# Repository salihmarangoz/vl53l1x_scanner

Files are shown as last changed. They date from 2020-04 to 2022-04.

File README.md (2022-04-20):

# VL53L1X Scanner (Abandoned Project)

   * [VL53L1X Scanner (Abandoned Project)](#vl53l1x-scanner-abandoned-project)
      * [1. Introduction](#1-introduction)
      * [2. Making the Scanner](#2-making-the-scanner)
      * [3. Installing the Software](#3-installing-the-software)
      * [4. Running](#4-running)
      * [5. Notes](#5-notes)
      * [6. References](#6-references)

## 1. Introduction

**Note:** This project is abandoned. The code works well but the hardware selection is poor. Single VL53L1X is too slow and stepper motor has problems. Althought, the code can be used as a reference.

This is my DIY laser scanner project that I designed in quarantine days of covid-19.  I aim to demonstrate the capabilities of VL53L1X range finder sensor and design a 2D/3D scanner and depth camera.

**Features:**

- ROS Driver
- 2D and 3D scanning mode (~1500 step in horizontal ~270 deg fov / 13 step in vertical ~27 deg fov)
- Resets stepper motor position to 0 when the driver is terminated
- Depth camera mode
- Stepper One Phase/Two Phase Mode
- Adaptive Scanning
  - Adaptive stepper resolution based on the measurement

## 2. Making the Scanner

Materials should be placed on to the breadboard and connections should be made as it is shown in the pictures below:

**Requirements:**

- VL53L1X  ToF Laser Distance Sensor
- 28BYJ-48 Stepper Motor and its driver board (ULN2003APG)
- A header for stepper motor (I used servo motor header)
- Arduino UNO
- Breadboard & Jumper Cables
- Hot glue & Adhesive Tape
- PC and USB Cable for Arduino (Will be used in `Installing the Software` section)

**Connection Diagram:**

- (Blue) `Arduino D9` **<=>** `Stepper motor driver IN1`
- (Blue) `Arduino D10` **<=>** `Stepper motor driver IN2`
- (Blue) `Arduino D11` **<=>** `Stepper motor driver IN3`
- (Blue) `Arduino D12` **<=>** `Stepper motor driver IN4`
- (Cyan) `Arduino SDA` **<=>** `VL53L1X SDA`
- (Cyan) `Arduino SCL` **<=>** `VL53L1X SCL`
- (Red) `Arduino 5V` **<=>** `Stepper Motor Driver 5V` **<=>** `VL53L1X VIN`
- (Black) `Arduino GND` **<=>** `Stepper Motor Driver GND` **<=>** `VL53L1X GND`
- (Colorful) `Stepper Motor Driver` **<=>** `Stepper Motor`

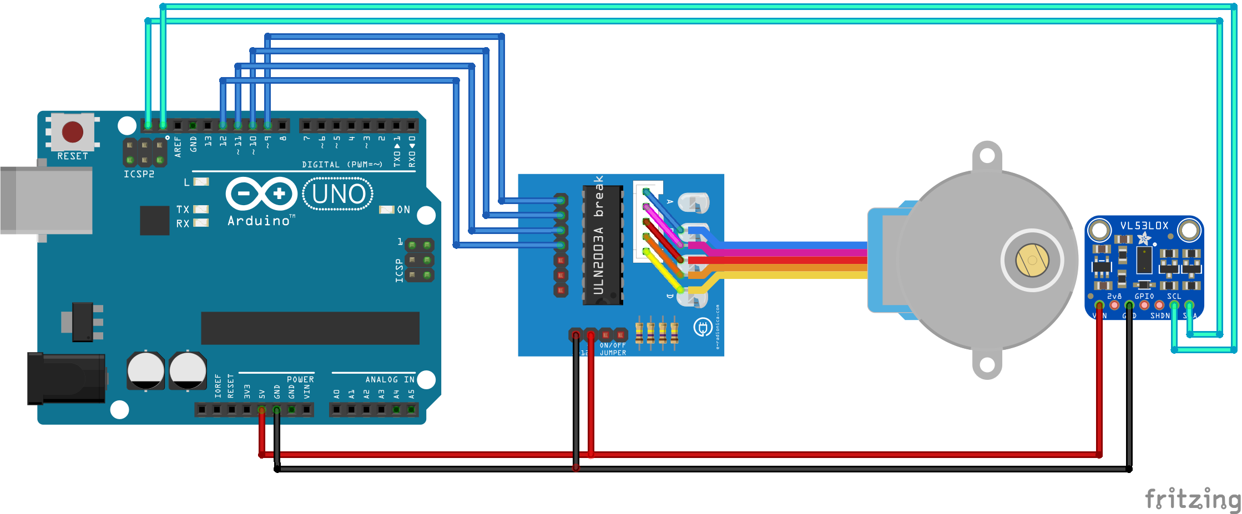
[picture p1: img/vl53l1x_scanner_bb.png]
vl53l1x_scanner_bb


**Result:**

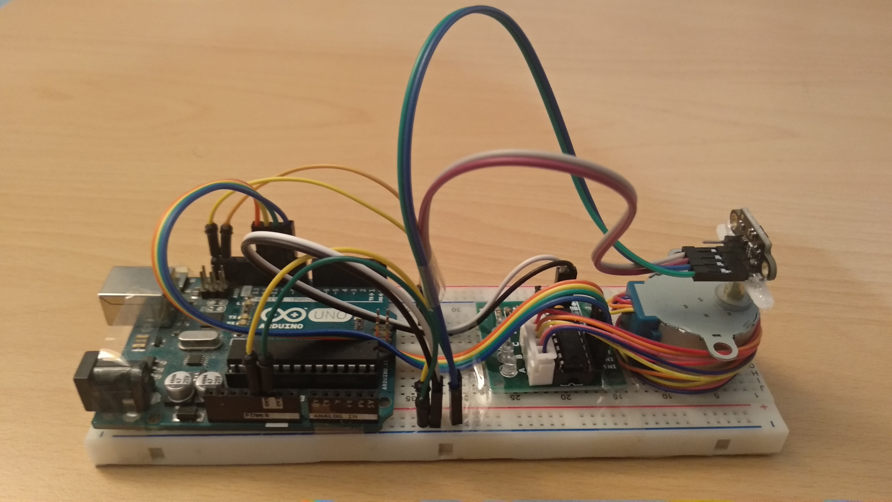
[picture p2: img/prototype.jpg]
prototype


## 3. Installing the Software

**Requirements:**

- Ubuntu 18.04 & ROS Melodic

- Arduino IDE 1.8.12
- VL53L1X API (https://www.st.com/en/embedded-software/stsw-img007.html#get-software)

**Installing:**

- Add user to dialout group then restart the PC:

```bash
$ sudo adduser $USER dialout
```

- Clone the project into `catkin_ws`:

```bash
$ mkdir -p ~/catkin_ws/src
$ cd ~/catkin_ws/src
$ git clone https://github.com/salihmarangoz/vl53l1x_scanner.git
```

- Compile the project:

```bash
$ cd ~/catkin_ws
$ catkin_make # or "catkin build"
```

- Extract the API folder (`vl53l1_api`) into `~/Arduino/libraries/` (Link in the requirements section)
- Upload the Arduino code using Arduino IDE: `~/catkin_ws/src/vl53l1x_scanner/arduino_code/vl53l1x_scanner_arduino/vl53l1x_scanner_arduino.ino`

## 4. Running

- Before running the systems, calibration process must be done if the laser is not faced forward:

```bash
$ cd ~/catkin_ws/src/vl53l1x_scanner/script/
# Positive for counter-clockwise or negative for clockwise rotation.
# The value "+100" is an example for positive rotation. Try "-100".
# As a result, laser should be facing forward.
# NOTE: May not work at the first try.
$ ./calibrate.sh /dev/ttyACM0 +100   
```

- Run the scanner driver:

```bash
$ source ~/catkin_ws/devel/setup.bash

# TO START THE DRIVER SELECT ONE:
$ roslaunch vl53l1x_scanner start_2d_laserscan.launch
$ roslaunch vl53l1x_scanner start_2d_pointcloud.launch # <- preffered
$ roslaunch vl53l1x_scanner start_3d_pointcloud.launch
$ roslaunch vl53l1x_scanner start_depth_camera.launch

# OR;

# TO INVESTIGATE PRE-RECORDED BAGS SELECT ONE:
$ roslaunch vl53l1x_scanner bag_2d.launch
$ roslaunch vl53l1x_scanner bag_3d.launch
```

- Run RViz:

```bash
$ roslaunch vl53l1x_scanner rviz.launch
```

## 5. References

- Stepper Driver Documentation: http://eeshop.unl.edu/pdf/Stepper+Driver.pdf
- VL53L1X ROI Documentation: https://www.st.com/resource/en/application_note/dm00516219-using-the-programmable-region-of-interest-roi-with-the-vl53l1x-stmicroelectronics.pdf
- Stepper and its Driver Fritzing Files: https://github.com/e-radionicacom/e-radionica.com-Fritzing-Library-parts-

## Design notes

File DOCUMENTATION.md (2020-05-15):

# VL53L1X Scanner Code Documentation

UNDER CONSTRUCTION!

### 1. Adaptive Scan Resolution

Optimizes angle between scans based on the previous single measurement. 

**Pros:**

- Is good for real-time operations (i.e. localization)
- Gives results faster
- Gives less data but with similar information

**Cons:**

- Outputs PointCloud2. Needs resampling for LaserScan message.
- May miss some measurements on edges of an object.

**Math:**

(1) Finding theta. Assuming that two scans will have same measurements. Applying cosines theorem.

adaptive_res_1

(2) In boundaries of the hardwares, `theta = f(dist)` has **reciprocal distribution** features. After removing the effect of this property, applying line fitting to find coefficients. See `/scripts/adaptive_scan_resolution_find_coefficients.py`

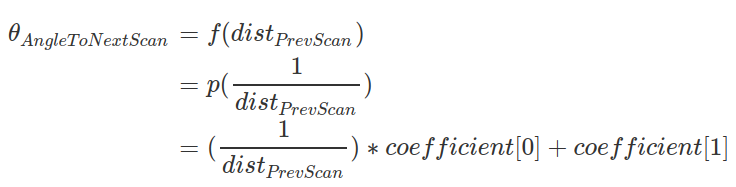
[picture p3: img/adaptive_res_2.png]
adaptive_res_2


(3) Line fitting result of `theta = p(1/dist)`

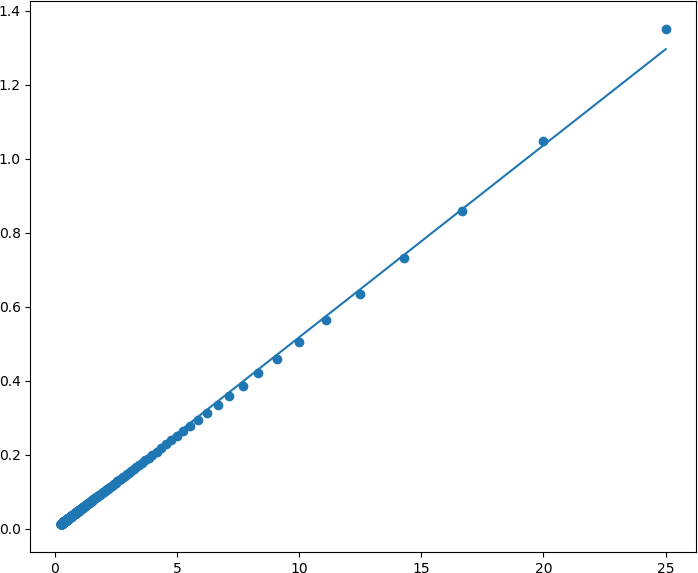
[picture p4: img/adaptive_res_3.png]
adaptive_res_3


**Note:**

Actually, I have tried predicting orientation of the wall to guess the direction of next measurement, but it failed. To explain it, firstly, rapid changes in the measurements caused fluctuations in guessed orientation of walls. Secondly, I have solved this issue with applying exponentially weighted averages on to the guess of wall orientation, but this caused overshoot at the end of walls. As a result, I have quit working with orientation predictions and came with this idea which is simpler and faster.

## 2. PointCloud Calculation

- Math calculation for measurement to pointcloud conversion:

pointcloud_calculation

--------------------------------------------------------------------------

## Notes

- Stepper motor delay set as 2.25ms instead of 2ms, because it was missing steps.
- (TODO) 28BYJ-48 steps per revolution is 2048 instead of 2038.

- Intensity value is equal to `signal_rate` (This may change in the future)

TODO:

- 3d best quality/speed parameters
- 2d best quality/speed parameters
- 2d select scan ring configuration

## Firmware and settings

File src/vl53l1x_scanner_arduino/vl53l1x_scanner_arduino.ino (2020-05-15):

#include <Wire.h>
#include "vl53l1_api.h"
#define __THIS_IS_THE_SCANNER__
#include "shared_conf.h"

//-------------------- GLOBAL VARIABLES ---------------------------------------
VL53L1_Dev_t sensor;
VL53L1_UserRoi_t roiConfig;
VL53L1_RangingMeasurementData_t rangingData;
int stepper_pos = 0; // managed by oneStep and calibration section
bool is_active = false;
bool is_initialized = false;
bool is_first_scan_received = false;
char* input_string;
int input_size = 0;
int scanner_direction = 1;
int desired_step = 0;

//==============================================================================
//=== SETUP & LOOP =============================================================
//==============================================================================

void setup()
{
  // Setup arduino
  input_string = (char*)malloc(ARDUINO_INPUT_STRING_SIZE*sizeof(char)); // I was unable to decleare it in stack memory. I don't know why
  if (input_string == NULL)
  {
    Serial.print(F("# FATAL ERROR: CANT ALLOCATE INPUT STRING IN MEMORY"));
  }
  input_string[ARDUINO_INPUT_STRING_SIZE-1] = '\0';
	Serial.begin(ARDUINO_SERIAL_BAUD_RATE);
  while (!Serial) {;} // wait for serial port to connect.
}


void loop()
{
  if (is_active && is_initialized)
  {
    scanState();
    actionState();
  }
}

//==============================================================================
//=== SCANNER STATE ============================================================
//==============================================================================

void actionState()
{
    if (p_scanner_mode == SCAN_MODE_CAM_DEPTHIMAGE)
    {
      Serial.println(F("$")); // FULL SCAN HEADER
    }
    // REWIND
    else if (p_scanner_rewind && stepper_pos >= p_stepper_step_max)
    { 
      Serial.println(F("$+")); // FULL SCAN HEADER
      is_first_scan_received = false;
      stepperStep(-stepper_pos+p_stepper_step_min, p_stepper_delay);
    } 
    // CHANGE DIRECTION
    else if ( !p_scanner_rewind && ((stepper_pos >= p_stepper_step_max && scanner_direction > 0) || (stepper_pos <= p_stepper_step_min && scanner_direction < 0)) )
    {
      Serial.print(F("$")); // FULL SCAN HEADER
      scanner_direction = -scanner_direction;
      if (scanner_direction>0)
        Serial.println(F("+"));
      else
        Serial.println(F("-"));
    }
    else
    {
      // default:
      desired_step = scanner_direction*p_scanner_horizontal_steps;

      // adaptive resolution (only compatible with SCAN_MODE_2D_POINTCLOUD)
      if (p_adaptive_resolution_enable && is_first_scan_received && p_scanner_mode == SCAN_MODE_2D_POINTCLOUD)
      {
        float distance = (float(rangingData.RangeMilliMeter)/1000.0);
        float adaptive_angle = (1.0/distance)*p_adaptive_resolution_coef_0 + p_adaptive_resolution_coef_1;
        float step_per_angle = 1.0 / p_stepper_horizontal_angle_per_step;
        float target_step = adaptive_angle * step_per_angle;
        if (abs(int(target_step)) <= 0)
          target_step = 1;
        desired_step = abs(int(target_step)) * scanner_direction;
      }

      //Serial.print("# desired_step ");
      //Serial.println(desired_step);
      stepperStep(desired_step, p_stepper_delay);
    }
}


void scanState()
{
  switch (p_scanner_mode)
  {
    case SCAN_MODE_2D_LASERSCAN: scan2D(); break;
    case SCAN_MODE_2D_POINTCLOUD: scan2D(); break;
    case SCAN_MODE_3D_POINTCLOUD: scan3D(); break;
    case SCAN_MODE_CAM_DEPTHIMAGE: scanCamera(); break;
    default: Serial.println(F("# ERROR: Unknown scanner_mode"));
  }
}

//==============================================================================
//=== SCAN MODES ===============================================================
//==============================================================================

void scan2D()
{
  measureDistance(stepper_pos, 0, false, -1, -1, -1, -1);
}

void scan3D()
{
  for (int i=0; i<13; i+=p_scanner_vertical_steps)
  {
    measureDistance(stepper_pos, i+LASER_VERTICAL_POS_BIAS, true, p_laser_roi_topleftx, i+3, p_laser_roi_botrightx, i);
  }
}

void scanCamera()
{
  for (int i=12; i>=0; i-=p_scanner_vertical_steps)
  {
    for (int j=12; j>=0; j-=p_scanner_horizontal_steps)
    {
      measureDistance(j+LASER_HORIZONTAL_POS_BIAS, i+LASER_VERTICAL_POS_BIAS, true, j, i+3, j+3, i); // hori, vert
    }
    
  }
}


//==============================================================================
//=== COMMUNICATION & INITIALIZTION ============================================
//==============================================================================

void serialEvent()
{
  while (Serial.available())
  {
    char in_char = (char)Serial.read();
    if (in_char != '\n')
    {
      input_string[input_size] = in_char;
      input_size++;
    }
    else
    {
      input_string[input_size] = '\0';
      ////////// PROCESS INPUT HERE //////////
      // How to use this device: I -> C (optional) -> S -> P
      // V -> set variables
      // I -> initialize
      // C -> calibration
      // S -> start
      // P -> poweroff
      // Serial.println(input_string); // debug
      char* token = strtok(input_string, " ");

      if (token[0] == 'V') // I was unable to use switch statement here. It didn't work and I don't know why
      {
        static bool first_time = true;
        if (first_time)
        {
          Serial.println(F("# ===== SET VARIABLE COMMAND ====="));
          first_time = false;
        }
        token = strtok(NULL, " ");
        PROCESS_PARAMETER(atoi(token));
      }
      else if (token[0] == 'I')  
      {
        Serial.println(F("# ===== INITIALIZE COMMAND ====="));
        initialize_hardware();
      }
      else if (token[0] == 'C')
      {
        Serial.println(F("# ===== CALIBRATION COMMAND ====="));
        token = strtok(NULL, " ");
        int calib_command = atoi(token);
        if (calib_command > p_scanner_calibration_max_value) calib_command = p_scanner_calibration_max_value;
        if (calib_command < -p_scanner_calibration_max_value) calib_command = -p_scanner_calibration_max_value;
        stepperStep(calib_command, p_stepper_delay);
        stepper_pos = 0;
      }
      else if (token[0] == 'S')
      {
        Serial.println(F("# ===== START COMMAND ====="));
        if (p_scanner_mode != SCAN_MODE_CAM_DEPTHIMAGE)
          stepperStep(p_stepper_step_min, p_stepper_delay); // bring stepper to pos 0
        is_active = true;
        Serial.println("$+"); // FULL SCAN HEADER
      }
      else if (token[0] == 'P')
      {
        Serial.println(F("# ===== SHUTDOWN COMMAND ====="));
        is_active = false;
        stepperStep(-stepper_pos, p_stepper_delay); // bring stepper to pos 0
        digitalWrite(p_stepper_pin_1, LOW);
        digitalWrite(p_stepper_pin_2, LOW);
        digitalWrite(p_stepper_pin_3, LOW);
        digitalWrite(p_stepper_pin_4, LOW);
      }
      
      ////////////////////////////////////////
      
      input_string[0] = '\0';
      input_size = 0;
    } 
  }
}


void initialize_hardware()
{  
  Serial.println(F("# [Init Hardware]"));
  // Initialize Stepper
  Serial.println(F("#   Initializing Stepper"));
  delay(100);
  pinMode(p_stepper_pin_1, OUTPUT);
  pinMode(p_stepper_pin_2, OUTPUT);
  pinMode(p_stepper_pin_3, OUTPUT);
  pinMode(p_stepper_pin_4, OUTPUT);

  // Initialize VL53L1X
  Serial.println(F("#   Initializing VL53L1X"));
  delay(100);
  Wire.begin();
  Wire.setClock(LASER_WIRE_CLOCK);
  sensor.I2cDevAddr   = LASER_DEVICE_ADDR;
  roiConfig.TopLeftX  = p_laser_roi_topleftx;
  roiConfig.TopLeftY  = p_laser_roi_toplefty; //9
  roiConfig.BotRightX = p_laser_roi_botrightx;
  roiConfig.BotRightY = p_laser_roi_botrighty; // 6
  check( VL53L1_software_reset(&sensor) );
  check( VL53L1_WaitDeviceBooted(&sensor) );
  check( VL53L1_DataInit(&sensor) );
  check( VL53L1_StaticInit(&sensor) );
  check( VL53L1_SetDistanceMode(&sensor, p_laser_distance_mode) ); // VL53L1_DISTANCEMODE_LONG
  check( VL53L1_SetMeasurementTimingBudgetMicroSeconds(&sensor, p_laser_measurement_timing_budget_micro_seconds) ); // 50000
  check( VL53L1_SetInterMeasurementPeriodMilliSeconds(&sensor, p_laser_inter_measurement_period_milli_seconds) ); // 50
  check( VL53L1_SetUserROI(&sensor, &roiConfig) );
  check( VL53L1_StartMeasurement(&sensor) );

  Serial.println(F("# [Read VL53L1X Information]"));

  // device version/model information
  uint8_t byteData;
  check( VL53L1_RdByte(&sensor, 0x010F, &byteData) );
  Serial.print(F("#   Model ID: "));
  Serial.println(byteData, HEX);
  check( VL53L1_RdByte(&sensor, 0x0110, &byteData) );
  Serial.print(F("#   Module Type: "));
  Serial.println(byteData, HEX);

  uint8_t product_rev_major, product_rev_minor;
  check( VL53L1_GetProductRevision(&sensor, &product_rev_major, &product_rev_minor) );
  Serial.print(F("#   Product Revision: "));
  Serial.print(product_rev_major);
  Serial.print(F("."));
  Serial.println(product_rev_minor);

  VL53L1_Version_t version_inf;
  check( VL53L1_GetVersion(&version_inf) );
  Serial.print(F("#   API Version: "));
  Serial.print(version_inf.major);
  Serial.print(F("."));
  Serial.print(version_inf.minor);
  Serial.print(F(" build "));
  Serial.print(version_inf.build);
  Serial.print(F(" revision "));
  Serial.println(version_inf.revision);

  long unsigned int optical_center_x, optical_center_y;
  check( VL53L1_GetOpticalCenter(&sensor, &optical_center_x, &optical_center_y) );
  Serial.print(F("#   Optical Center X: "));
  Serial.println(optical_center_x);
  Serial.print(F("#   Optical Center Y: "));
  Serial.println(optical_center_y);

  is_initialized = true;
}

//==============================================================================
//=============== RANGE FINDER =================================================
//==============================================================================

void measureDistance(int horizontal_pos, int vertical_pos, bool update_roi, int roi_topleftx, int roi_toplefty, int roi_botrightx, int roi_botrighty)
{
  if (update_roi)
  {
    roiConfig.TopLeftX  = roi_topleftx;
    roiConfig.TopLeftY  = roi_toplefty;
    roiConfig.BotRightX = roi_botrightx;
    roiConfig.BotRightY = roi_botrighty;
  }
  
  check( VL53L1_SetUserROI(&sensor, &roiConfig) );
  check( VL53L1_clear_interrupt_and_enable_next_range(&sensor, VL53L1_DEVICEMEASUREMENTMODE_SINGLESHOT));
  check( VL53L1_WaitMeasurementDataReady(&sensor) );
  check( VL53L1_GetRangingMeasurementData(&sensor, &rangingData) );
  
  Serial.print(horizontal_pos); // horizontal pos
  Serial.print(F(" "));
  Serial.print(vertical_pos);   // vertical pos
  Serial.print(F(" "));
  Serial.print(rangingData.RangeMilliMeter);
  Serial.print(F(" "));
  Serial.print(rangingData.RangeStatus);
  Serial.print(F(" "));
  Serial.print(rangingData.SignalRateRtnMegaCps/65536.0);
  Serial.print(F(" "));
  Serial.println(rangingData.AmbientRateRtnMegaCps/65336.0);

  is_first_scan_received = true;
}

//==============================================================================
//=============== STEPPER ======================================================
//==============================================================================

void stepperStep(int movement, unsigned long delay_time){
  if (movement >= 0)
    for (int i=0; i<movement; i++)
      oneStep(true, delay_time);
  else
    for (int i=0; i<-movement; i++)
      oneStep(false, delay_time);
}

// full step / one phase
// Because we don't need two phases and also mine stepper motor was missing steps with two phases and/or half-step 
void oneStep(bool dir, unsigned long delay_time){
  static int step_number = 0;
  static unsigned long last_movement_time = 0;
  
  if(dir){
    stepper_pos++;
    switch(step_number)
    {
      case 0:
      digitalWrite(p_stepper_pin_1, LOW);
      digitalWrite(p_stepper_pin_2, LOW);
      digitalWrite(p_stepper_pin_3, STEPPER_TWO_PHASE);
      digitalWrite(p_stepper_pin_4, HIGH);
      break;
      case 1:
      digitalWrite(p_stepper_pin_1, LOW);
      digitalWrite(p_stepper_pin_2, STEPPER_TWO_PHASE);
      digitalWrite(p_stepper_pin_3, HIGH);
      digitalWrite(p_stepper_pin_4, LOW);
      break;
      case 2:
      digitalWrite(p_stepper_pin_1, STEPPER_TWO_PHASE);
      digitalWrite(p_stepper_pin_2, HIGH);
      digitalWrite(p_stepper_pin_3, LOW);
      digitalWrite(p_stepper_pin_4, LOW);
      break;
      case 3:
      digitalWrite(p_stepper_pin_1, HIGH);
      digitalWrite(p_stepper_pin_2, LOW);
      digitalWrite(p_stepper_pin_3, LOW);
      digitalWrite(p_stepper_pin_4, STEPPER_TWO_PHASE);
    } 
  }
  else
  {
    stepper_pos--;
    switch(step_number)
    {
      case 0:
      digitalWrite(p_stepper_pin_1, HIGH);
      digitalWrite(p_stepper_pin_2, LOW);
      digitalWrite(p_stepper_pin_3, LOW);
      digitalWrite(p_stepper_pin_4, STEPPER_TWO_PHASE);
      break;
      case 1:
      digitalWrite(p_stepper_pin_1, STEPPER_TWO_PHASE);
      digitalWrite(p_stepper_pin_2, HIGH);
      digitalWrite(p_stepper_pin_3, LOW);
      digitalWrite(p_stepper_pin_4, LOW);
      break;
      case 2:
      digitalWrite(p_stepper_pin_1, LOW);
      digitalWrite(p_stepper_pin_2, STEPPER_TWO_PHASE);
      digitalWrite(p_stepper_pin_3, HIGH);
      digitalWrite(p_stepper_pin_4, LOW);
      break;
      case 3:
      digitalWrite(p_stepper_pin_1, LOW);
      digitalWrite(p_stepper_pin_2, LOW);
      digitalWrite(p_stepper_pin_3, STEPPER_TWO_PHASE);
      digitalWrite(p_stepper_pin_4, HIGH);
      break;
    } 
  }
  step_number = (step_number+1) % 4;
  delayMicroseconds(delay_time);
}


//==============================================================================
//=============== UTILITY ======================================================
//==============================================================================

int check(int err)
{
  if (err != 0)
  {
    Serial.print(F("# ERROR: "));
    Serial.println(err);
  }
  return err;
}

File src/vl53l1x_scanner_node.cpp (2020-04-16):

#include <ros/ros.h>
#include <serial/serial.h>
#include <sensor_msgs/LaserScan.h>
#include <sensor_msgs/PointCloud2.h>
#include <cstring>
#include <vector>
#include <algorithm>

union PC_DATA_t
{
    struct
    {
        float x, y, z, intensity;
    }structured;
    uint8_t raw[16];
};

// Global Variables
serial::Serial ser;
char read_buffer[512];
char write_buffer[512];
ros::Publisher laser_pub;
ros::Publisher pc_pub;
sensor_msgs::LaserScan laser_scan;
sensor_msgs::PointCloud2 pc_scan; 
bool laser_scan_direction;


// Hardware specific
double stepper_horizontal_angle_per_step = 0.003067962; // pi/1024 TODO
double laser_vertical_angle_per_roi_cell = 0.035; // TODO
double laser_range_min = 0.0;
double laser_range_max = 4.0; // TODO


// ROS specific
std::string laserscan_frame = "laser";


// Scanner specific
int stepper_pin_1 = 9;
int stepper_pin_2 = 10;
int stepper_pin_3 = 11;
int stepper_pin_4 = 12;
int stepper_delay = 2250; // my stepper motor misses step with 2000. So I added extra 250
int stepper_step_min = -300;
int stepper_step_max = +300;
int laser_distance_mode = 3; // ADAPTIVE(0), short(1), medium(2), long(3)
int laser_measurement_timing_budget_micro_seconds = 500000;
int laser_inter_measurement_period_milli_seconds = 50;
int scanner_3d_mode = 1;
int scanner_3d_vertical_steps_per_scan = 1;
int scanner_horizontal_steps_per_scan = 20;
int scanner_rewind = 1;
int scanner_calibration_max_value = 500;


void sendParameters();
void startScanning();
void stopScanning();
char* readLineFromDevice();
void process2D(char *line);
void process3D(char *line);


int main (int argc, char** argv)
{
    ros::init(argc, argv, "vl53l1x_scanner_node");
    ros::NodeHandle nh;
    ros::NodeHandle priv_nh("~");

    // Hardware specific
    priv_nh.param("stepper_horizontal_angle_per_step", stepper_horizontal_angle_per_step, stepper_horizontal_angle_per_step);
    priv_nh.param("laser_vertical_angle_per_roi_cell", laser_vertical_angle_per_roi_cell, laser_vertical_angle_per_roi_cell);
    priv_nh.param("laser_range_min", laser_range_min, laser_range_min);
    priv_nh.param("laser_range_max", laser_range_max, laser_range_max);
    

    // ROS specific
    priv_nh.param("laserscan_frame", laserscan_frame, laserscan_frame);

    // Scanner specific
    priv_nh.param("stepper_pin_1", stepper_pin_1, stepper_pin_1);
    priv_nh.param("stepper_pin_2", stepper_pin_2, stepper_pin_2);
    priv_nh.param("stepper_pin_3", stepper_pin_3, stepper_pin_3);
    priv_nh.param("stepper_pin_3", stepper_pin_3, stepper_pin_3);
    priv_nh.param("stepper_delay", stepper_delay, stepper_delay);
    priv_nh.param("stepper_step_min", stepper_step_min, stepper_step_min);
    priv_nh.param("stepper_step_max", stepper_step_max, stepper_step_max);
    priv_nh.param("laser_distance_mode", laser_distance_mode, laser_distance_mode);
    priv_nh.param("laser_measurement_timing_budget_micro_seconds", laser_measurement_timing_budget_micro_seconds, laser_measurement_timing_budget_micro_seconds);
    priv_nh.param("laser_inter_measurement_period_milli_seconds", laser_inter_measurement_period_milli_seconds, laser_inter_measurement_period_milli_seconds);
    priv_nh.param("scanner_3d_mode", scanner_3d_mode, scanner_3d_mode);
    priv_nh.param("scanner_3d_vertical_steps_per_scan", scanner_3d_vertical_steps_per_scan, scanner_3d_vertical_steps_per_scan);
    priv_nh.param("scanner_horizontal_steps_per_scan", scanner_horizontal_steps_per_scan, scanner_horizontal_steps_per_scan);
    priv_nh.param("scanner_rewind", scanner_rewind, scanner_rewind);
    priv_nh.param("scanner_calibration_max_value", scanner_calibration_max_value, scanner_calibration_max_value);

    if (scanner_3d_mode)
    {
        pc_pub = nh.advertise<sensor_msgs::PointCloud2>("vl53l1x_points", 2);
    }
    else
    {
        laser_pub = nh.advertise<sensor_msgs::LaserScan>("scan", 2);
    }

    try
    {
        ser.setPort("/dev/ttyACM0");
        ser.setBaudrate(9600);
        serial::Timeout to = serial::Timeout::simpleTimeout(1000);
        ser.setTimeout(to);
        ser.open();
    }
    catch (serial::IOException& e)
    {
        ROS_ERROR_STREAM("Unable to open port ");
        return -1;
    }

    if(ser.isOpen())
    {
        ROS_INFO_STREAM("Serial Port initialized");
    }else{
        return -1;
    }

    // Flush old buffer
    while(ser.available())
    {
        ser.read(1)[0];
    }

    ros::Duration(3.0).sleep(); // Wait for arduino

    sendParameters();

    ros::Duration(1.0).sleep(); // Wait for parameter responses

    startScanning();

    while (ros::ok())
    {
        char *line = readLineFromDevice();
        if (line == NULL) continue;

        if (line[0] == '#')
        {
            ROS_WARN("%s", line);
        }
        else if (scanner_3d_mode)
        {
            ROS_ERROR("%s", line);
            process3D(line);
        }
        else
        {
            ROS_ERROR("%s", line);
            process2D(line);
            //pub.publish(scan);
        }
    }

    stopScanning();

}


void sendParameters()
{
    sprintf(write_buffer, "I %d %d %d %d %d %d %d %d %d %d %d %d %d %d %d\n", stepper_pin_1, \
                                                                            stepper_pin_2, \
                                                                            stepper_pin_3, \
                                                                            stepper_pin_4, \
                                                                            stepper_delay, \
                                                                            stepper_step_min, \
                                                                            stepper_step_max, \
                                                                            laser_distance_mode, \
                                                                            laser_measurement_timing_budget_micro_seconds, \
                                                                            laser_inter_measurement_period_milli_seconds, \
                                                                            scanner_3d_mode, \
                                                                            scanner_3d_vertical_steps_per_scan, \
                                                                            scanner_horizontal_steps_per_scan, \
                                                                            scanner_rewind, \
                                                                            scanner_calibration_max_value);
    //ROS_INFO("WRITE: %s", write_buffer);
    ser.write(write_buffer); // Initialize
    ser.flush();
}

void startScanning()
{
    ser.write("S\n"); // Start Scanning
    ser.flush();
}

void stopScanning()
{
    ser.write("P\n"); // Shutdown
    ser.flush();
}
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

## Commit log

2020-04-16 added connection diagram
    [vl53l1x_scanner.fzz]
2020-04-16 added calibration feature
2020-04-17 added new data fields for 3d scan and fixed some issues
    [vl53l1x_scanner_arduino.ino, vl53l1x_scanner_driver_node.cpp]
2020-04-17 print vl53l1x information
2020-04-17 fixed some issues and modified comments
    [vl53l1x_scanner_driver_node.cpp]
2020-04-20 refactoring arduino code
    But parameter reading step is failed. Need to get parameters one by one. It is causing overflow
    [vl53l1x_scanner_arduino.ino, vl53l1x_scanner_driver_node.cpp]
2020-04-21 testing camera mode
2020-05-15 added depth_camera
    - changed to two phase stepper
    - added sensor_msgs/Image
    - refactored parameter names
    - refactored launch names
